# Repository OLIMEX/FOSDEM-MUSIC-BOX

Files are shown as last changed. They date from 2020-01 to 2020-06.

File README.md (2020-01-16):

# FOSDEM-MUSIC-BOX

Soldering kit programmable with Arduino IDE to play music

Product page: https://www.olimex.com/Products/Soldering-Kits/FOSDEM-MUSIC-BOX/open-source-hardware

## License
* Hardware is with CERN OHL v1.2 license
* Software is released under GPL3 License
* Documentation is released under CC BY-SA 3.0

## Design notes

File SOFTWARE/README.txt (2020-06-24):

FOSDEM-MUSIC-BOX software for Arduino IDE 1.8.10

Notice that the chip comes pre-loaded and to play the demo sound you don't need to 
reprogram it - just touch the light sensor!

You need to install the Olimex package first, else you would encounter compilation issues.

Please do the following:

1) Navigate to Main Menu --> File --> Preferences

In "Additional Boards Managers IRLs" add our JSON link:

https://raw.githubusercontent.com/OLIMEX/Arduino_configurations/master/AVR/package_olimex_avr_index.json

2) Navigate to Main Menu --> Tools --> Board --> Boards Manager (if you want to filter the packages you can type in the search "Olimex")

Select Olimex AVR boards and then install (up to 2020/01/30 the latest version is 2.0.2)

3) Main Menu --> Tools --> Board --> Olimexino-85

4) Compile

5) Unplug the board

6) Upload

7) Plug the board to the USB

8) Wait until the program uploads and then few seconds to leave the bootloader mode (at the start of the program the red LED should blink once)

9) After the LED blinks the program will get some samples from the light sensor and then when it's dimmed a simple track will be played (by default it's short version of Mario bros theme).

10) You can change it by comment/uncomment different tracks within the loop function or create your own using the available ones in the "Tracks" folder as an example.

YYYY/MM/DD
2020/01/30

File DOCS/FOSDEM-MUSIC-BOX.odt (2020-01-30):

FOSDEM MUSIC BOX – Assembly cheatsheet

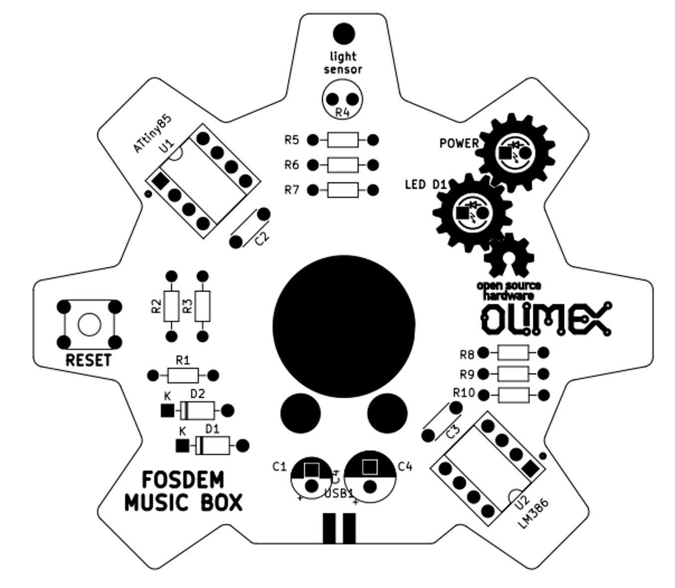
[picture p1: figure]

1. Resistors

R2, R3, R8 – 22R – 1/8W 5% - RED-RED-BLACK-GOLD

R1, R6, R9 – 1.5K – 1/8W 5% - BROWN-GREEN-RED-GOLD

R5, R7, R10 – 10K – 1/8W 5% - BROWN-BLACK-ORANGE-GOLD

2. Diodes

D1, D2 - 1N4148 – Warning! Polarity matters! Black stripe should be placed at the (K)athode side.

3. IC sockets

The first pin is marked!

U1 – ATTiny85 – Warning! Polarity matters! Orient properly!

U2 – LM386 – Warning! Polarity matters! Orient properly!

4. Button

RESET – 4-pin button

5. Speaker

SOLDER THE SPEAKER CAREFULLY! DO NOT OVERHEAT!

Hold soldering iron for NO more than 3 seconds soldering on pad or you will destroy the speaker.

6. USB connector – big metal shield pins soldering on bottom!

7. Capacitors

C2, C3 - 100nF X5R – 50VDC

C1 – 10uF 50VDC – Warning! Insert longer pin into circle pad.

C4 – 220uF 16VDC – Warning! Insert longer pin into circle pad.

8. LEDs

LED D1 – RED – Warning! Insert longer pin into circle pad

POWER – GREEN(clear) – Warning! Insert longer pin into circle pad

9. Light Sensor

R4 – 10K LDR

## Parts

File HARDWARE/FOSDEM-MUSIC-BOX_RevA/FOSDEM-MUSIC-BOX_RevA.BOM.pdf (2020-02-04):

FOSDEM-MUSIC-BOX_RevA

Designation | Quantity | Designator
ИС ATTINY85-20PU | 1 | U1
SNS-LDR5MM | 1 | R4
SPEAKER-29-8-0.25 | 1 | SPK1
КЛЮЧ ТАКТИЛЕН T1102 6x6x4.3mm | 1 | SW1
ДИОД 1N4148 | 2 | D1, D2
ИС LM386N-1 | 1 | U2
КОНДЕНЗАТОР 10 uF 16V | 1 | C1
КОНДЕНЗАТОР 100 nF 25 V - 2010 | 2 | C2, C3
КОНДЕНЗАТОР 220 uF 16 V | 1 | C4
РЕЗИСТОР 1.5 K 1/8W 5% | 3 | R1, R6, R9
РЕЗИСТОР 10 K 1/8W 5% | 3 | R5, R7, R10
РЕЗИСТОР 22 OHM 1/8W 5% | 3 | R2, R3, R8
СВЕТОДИОД 3 MM ЗЕЛЕН 4000 mcd | 1 | LED2 – POWER
СВЕТОДИОД 3 MM ЧЕРВЕН 4000 mcd | 1 | LED1 – LED D1
СЪЕДИНИТЕЛ USB-SDWH-4B-LF (USB-B ПРАВ) | 1 | USB1

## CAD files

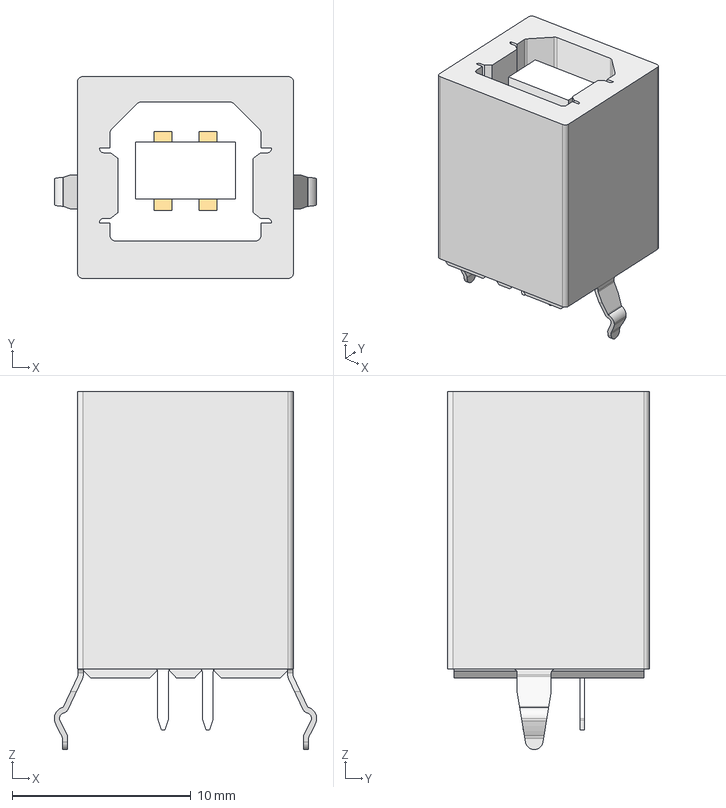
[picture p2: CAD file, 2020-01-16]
HARDWARE/FOSDEM-MUSIC-BOX_RevA/3d/usb_a-usb_b-top-c.stp
14.7 x 11.3 x 20.0 mm

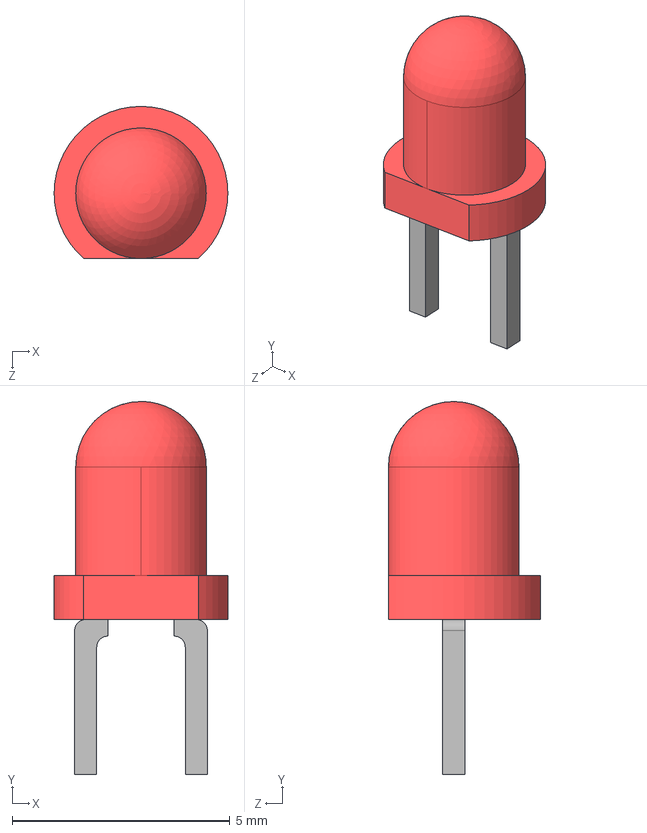
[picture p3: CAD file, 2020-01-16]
HARDWARE/FOSDEM-MUSIC-BOX_RevA/3d/REDLED.step
3.99 x 8.56 x 3.49 mm

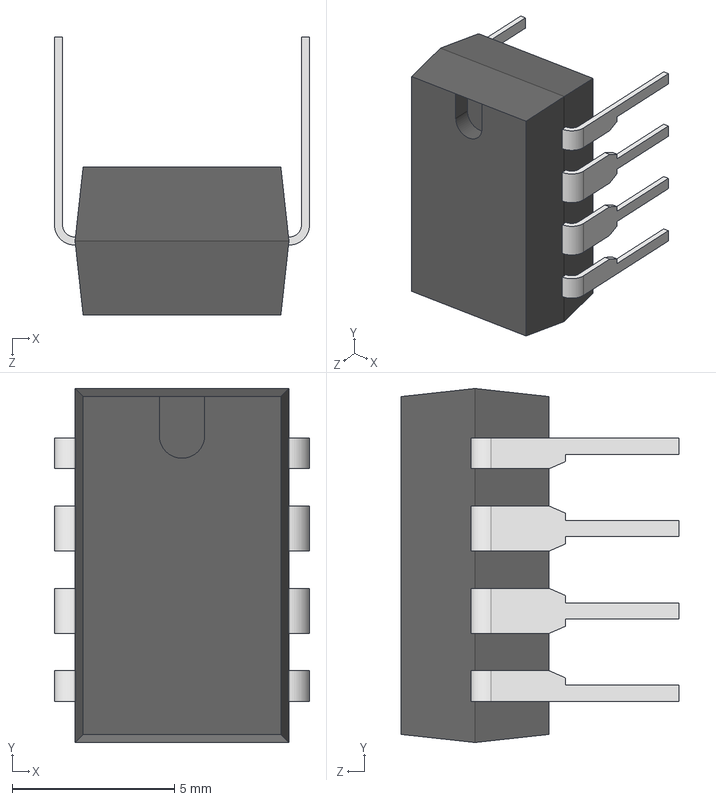
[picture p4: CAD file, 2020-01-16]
HARDWARE/FOSDEM-MUSIC-BOX_RevA/3d/DIP8_IC.step
7.87 x 10.9 x 8.58 mm

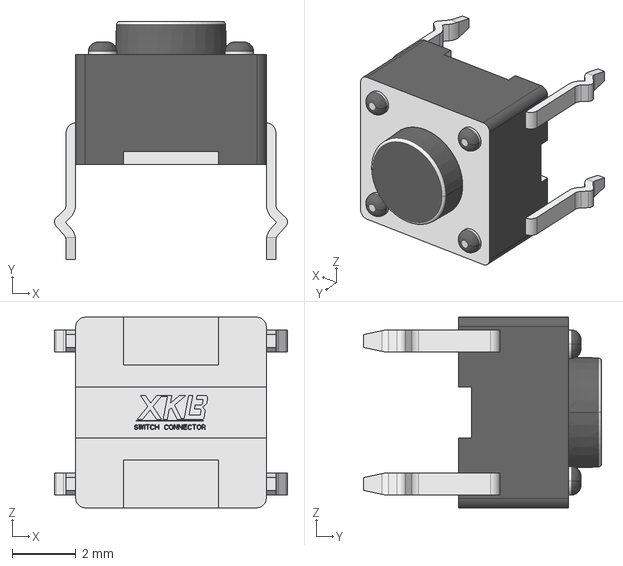
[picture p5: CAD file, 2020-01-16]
HARDWARE/FOSDEM-MUSIC-BOX_RevA/3d/t1102.step
7.34 x 7.50 x 6.00 mm

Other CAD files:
HARDWARE/FOSDEM-MUSIC-BOX_RevA/3d/GREENLED.step

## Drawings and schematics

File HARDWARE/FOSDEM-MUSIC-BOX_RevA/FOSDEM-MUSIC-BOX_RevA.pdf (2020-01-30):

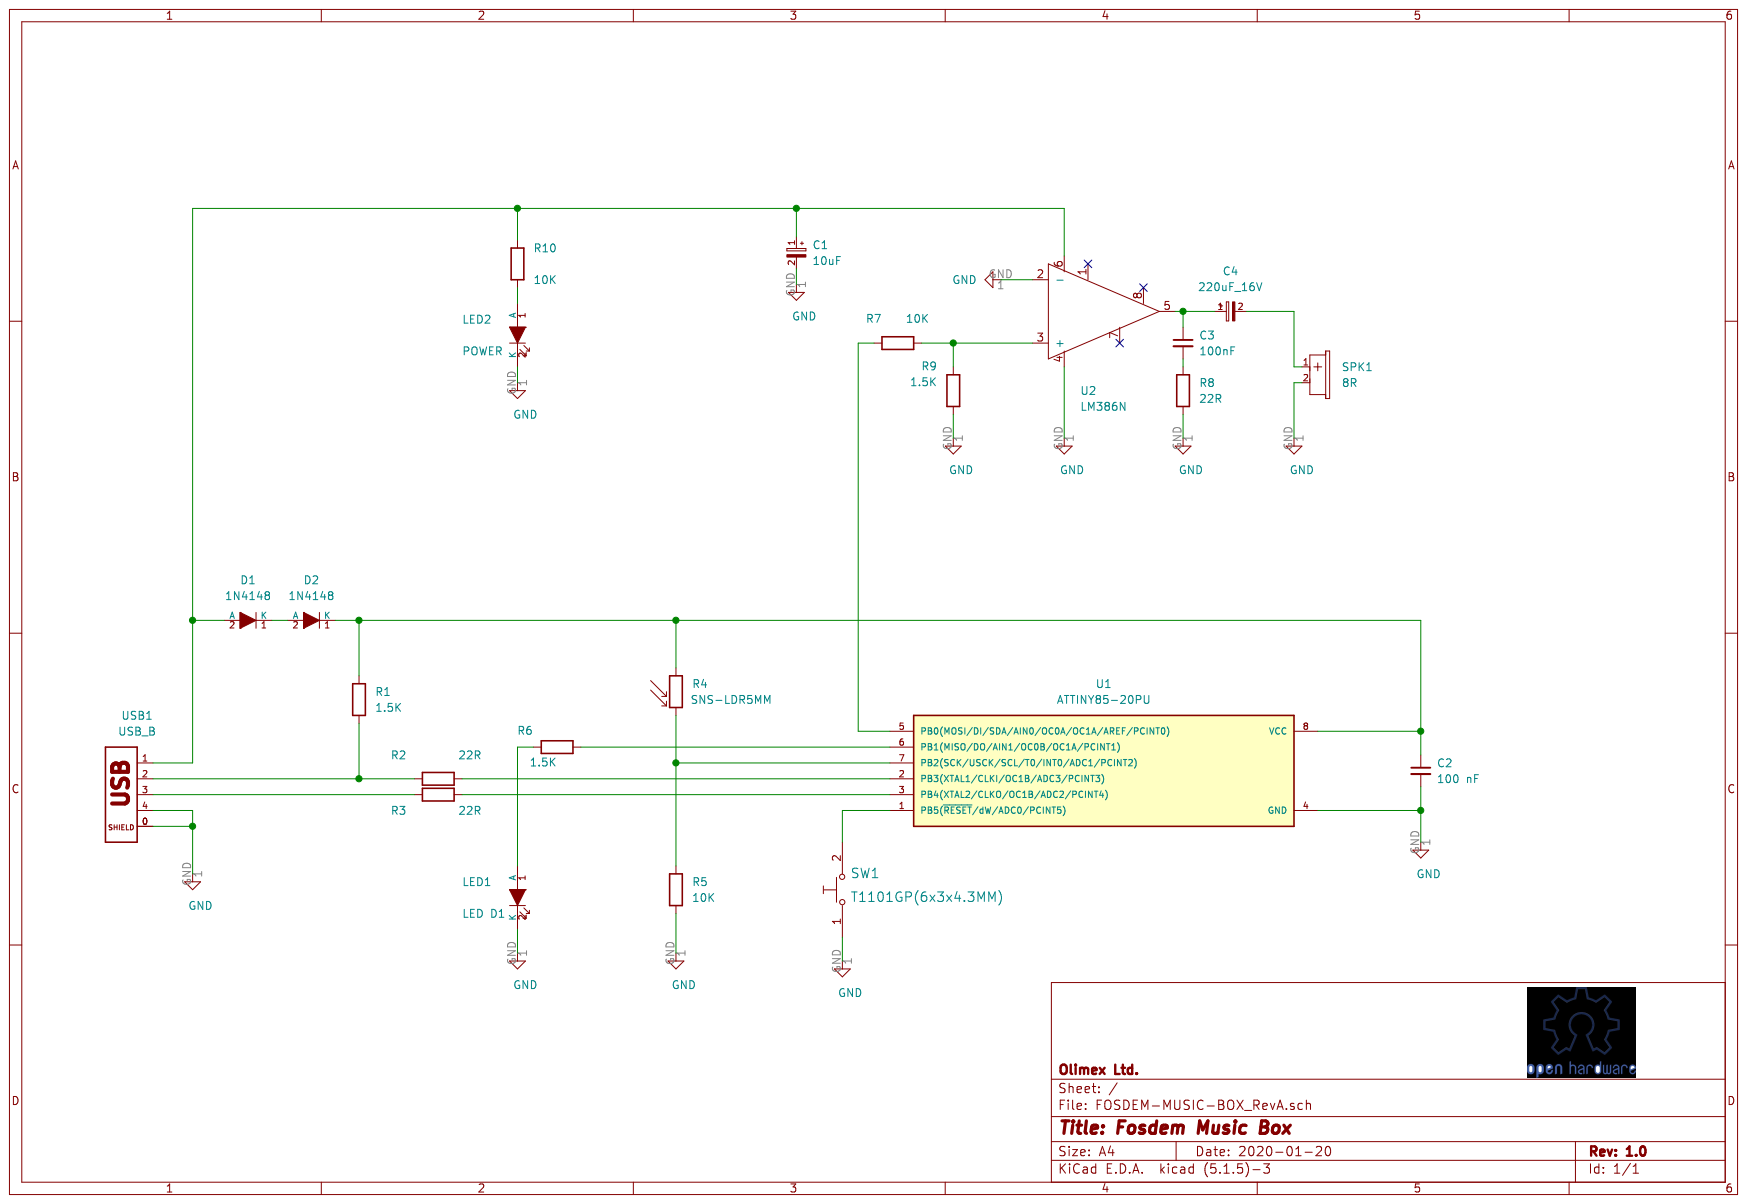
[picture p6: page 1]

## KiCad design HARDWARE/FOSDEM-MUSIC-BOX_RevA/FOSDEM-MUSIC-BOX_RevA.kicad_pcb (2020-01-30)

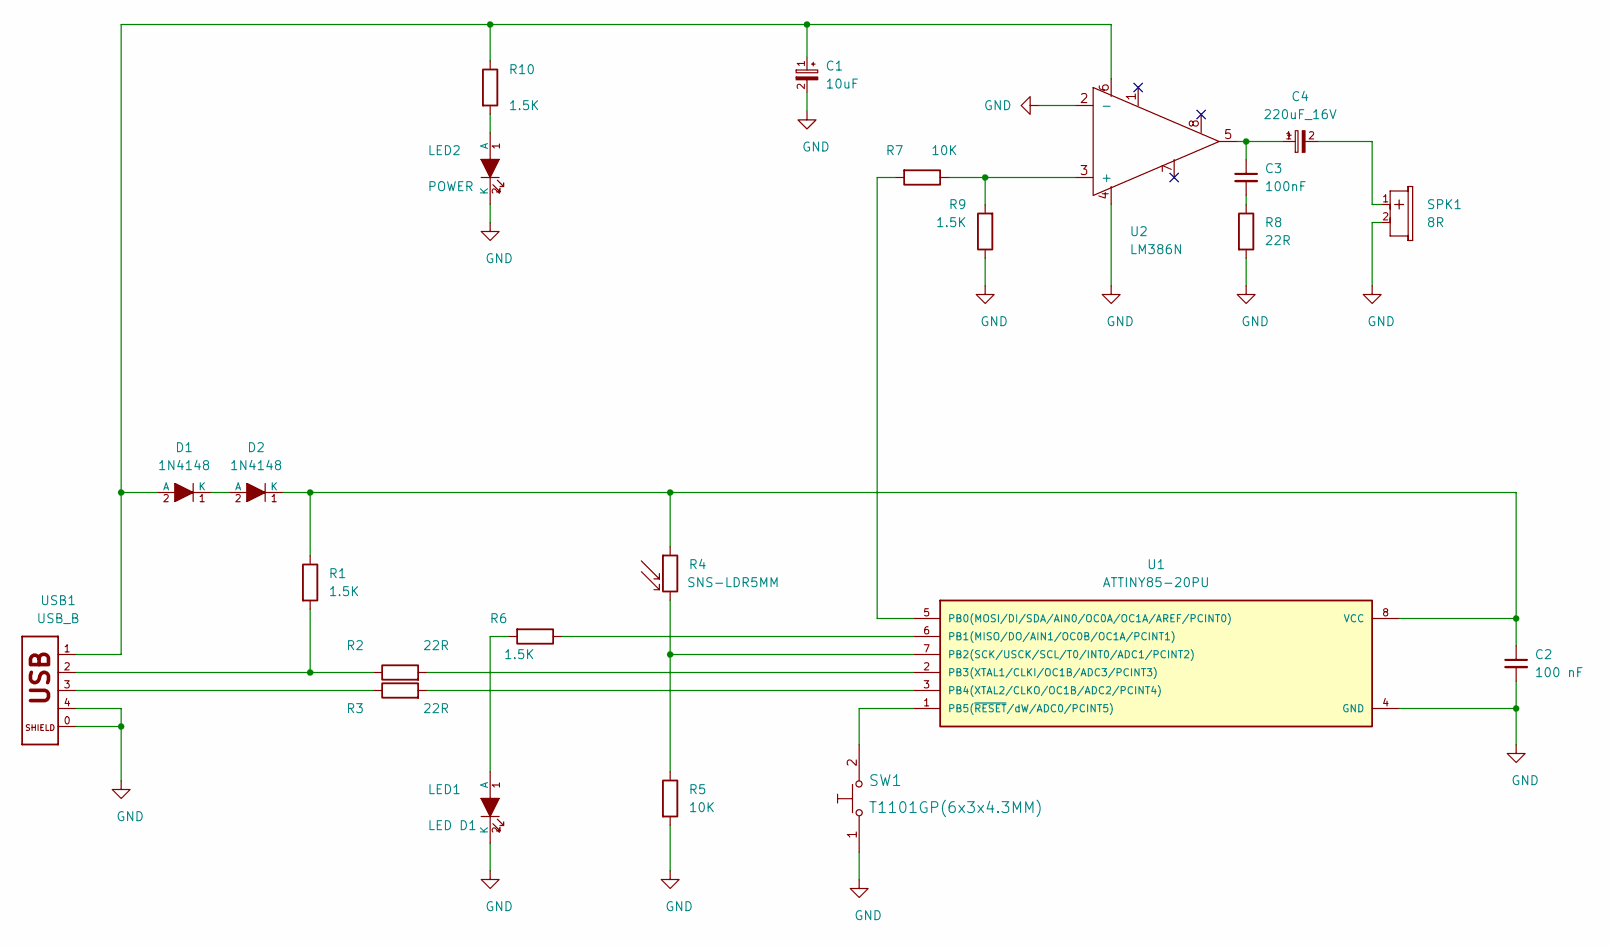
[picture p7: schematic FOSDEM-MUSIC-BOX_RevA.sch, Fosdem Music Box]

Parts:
C1: 10uF; CP_Radial_D5.0mm_P2.00mm
C2: 100 nF; C_Disc_D4.3mm_W1.9mm_P5.00mm
C3: 100nF; C_Disc_D4.3mm_W1.9mm_P5.00mm
C4: 220uF_16V; CP_Radial_D6.3mm_P2.50mm
D1, D2: 1N4148; D_DO-35_SOD27_P7.62mm_Horizontal
LED1: LED D1; LED-3mm-PTH-KA
LED2: POWER; LED-3mm-PTH-KA
R1, R6, R9, R10: 1.5K; R_Axial_DIN0204_L3.6mm_D1.6mm_P7.62mm_Horizontal
R2, R3, R8: 22R; R_Axial_DIN0204_L3.6mm_D1.6mm_P7.62mm_Horizontal
R4: SNS-LDR5MM; R_PHOTO
R5, R7: 10K; R_Axial_DIN0204_L3.6mm_D1.6mm_P7.62mm_Horizontal
SPK1: 8R; SPEAKER_28mm
SW1: T1101GP(6x3x4.3MM); T1102SMD
U1: ATTINY85-20PU; DIP-8_W7.62mm_Socket
U2: LM386N; DIP-8_W7.62mm_Socket
USB1: USB_B; USB-B-EDGE

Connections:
GND: C1.2 (-), C2.2, LED1.2 (K), LED2.2 (K), R5.2, R8.2, R9.1, SPK1.2 (MINUS), SW1.1, U1.4 (GND), U2.2 (-), U2.4, USB1.0 (5), USB1.4
unnamed: C1.1 (+), D1.2 (A), R10.1, U2.6, USB1.1
unnamed: C3.1, C4.1 (+), U2.5
unnamed: C3.2, R8.1
unnamed: C4.2 (-), SPK1.1 (PLUS)
unnamed: C2.1, D2.1 (K), R1.1, R4.1, U1.8 (VCC)
unnamed: D1.1 (K), D2.2 (A)
unnamed: LED1.1 (A), R6.2
unnamed: LED2.1 (A), R10.2
unnamed: R1.2, R2.1, USB1.2
unnamed: R2.2, U1.2 (PB3(XTAL1/CLKI/OC1B/ADC3/PCINT3))
unnamed: R3.1, USB1.3
unnamed: R3.2, U1.3 (PB4(XTAL2/CLKO/OC1B/ADC2/PCINT4))
unnamed: R6.1, U1.6 (PB1(MISO/DO/AIN1/OC0B/OC1A/PCINT1))
unnamed: R4.2, R5.1, U1.7 (PB2(SCK/USCK/SCL/T0/INT0/ADC1/PCINT2))
unnamed: R7.1, R9.2, U2.3 (+)
unnamed: R7.2, U1.5 (PB0(MOSI/DI/SDA/AIN0/OC0A/OC1A/AREF/PCI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)
unnamed: SW1.2, U1.1 (PB5(~RESET~/dW/ADC0/PCINT5))

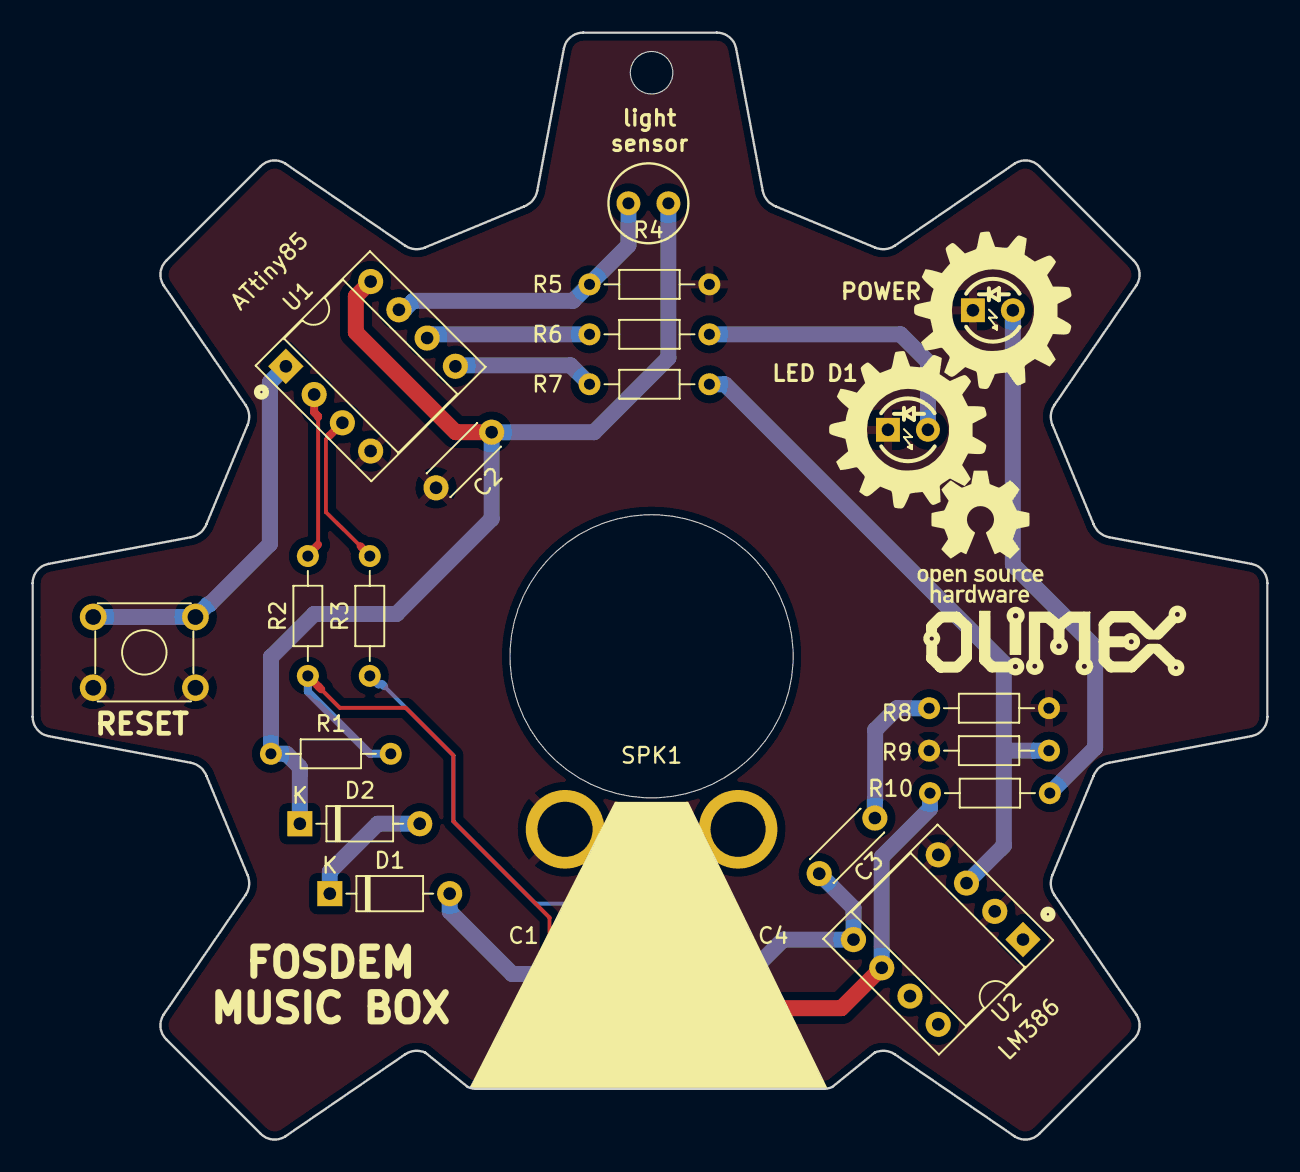
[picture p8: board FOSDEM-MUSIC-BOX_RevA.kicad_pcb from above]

Board: 2 copper layers, 78.5 x 70.4 mm, 24 parts (0 on the bottom side), 18 nets.

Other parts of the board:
MountingHole: NPTH_2.7mm

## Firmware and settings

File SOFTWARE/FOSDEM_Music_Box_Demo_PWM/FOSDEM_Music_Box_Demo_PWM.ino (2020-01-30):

#include "Notes.h"
#include "Tracks/All_Tracks.h"
#include "Speaker.h"

// the following functions just call the Play (in Speaker.cpp) function using the notes array from the respective file in "Tracks" folder
// Note: Since not all of them are made polyphonic, for some of them both channels are playing the same! If you want to play polyphonic on them edit the respective file
void Imperial_March ()
{
  Play (IM1_Note, IM1_Note, IM1_Duration, IM1_Tempo);
  Play (IM2_Note, IM2_Note, IM2_Duration, IM2_Tempo);
  Play (IMV1_Note, IMV1_Note, IMV1_Duration, IMV1_Tempo);
  Play (IM2_Note, IM2_Note, IM2_Duration, IM2_Tempo);
  Play (IMV2_Note, IMV2_Note, IMV2_Duration, IMV2_Tempo);
}

void Amazing_Grace ()
{
  Play (AG1_Note, AG1_Note, AG1_Duration, AG1_Tempo);
  Play (AG2_Note, AG2_Note, AG2_Duration, AG2_Tempo);
}

void Mario_Bros_Underwater ()
{
  Play (MBU1_Note, MBU1_Note, MBU1_Duration, MBU1_Tempo);
  Play (MBU2_Note, MBU2_Note, MBU2_Duration, MBU2_Tempo);
  Play (MBU3_Note, MBU3_Note, MBU3_Duration, MBU3_Tempo);
  Play (MBU4_Note, MBU4_Note, MBU4_Duration, MBU4_Tempo);
}

void Silent_Night_Holy_Night ()
{
  Play (SNHN1_Note, SNHN1_Note, SNHN1_Duration, SNHN1_Tempo);
  Play (SNHN2_Note, SNHN2_Note, SNHN2_Duration, SNHN2_Tempo);
  Play (SNHN3_Note, SNHN3_Note, SNHN3_Duration, SNHN3_Tempo);
}

void Test_audio ()
{
  Play (Test1_Note, Test1_Note, Test1_Duration, Test1_Tempo);
}

void Mario_Bros ()
{
  //     Channel0    Channel1
  Play (MB1_NoteC0, MB1_NoteC1, MB1_Duration, MB1_Tempo);
  Play (MB3_NoteC0, MB3_NoteC1, MB3_Duration, MB3_Tempo);
  Play (MB2_NoteC0, MB2_NoteC1, MB2_Duration, MB2_Tempo);
  Play (MB3_NoteC0, MB3_NoteC1, MB3_Duration, MB3_Tempo);
  Play (MB2_NoteC0, MB2_NoteC1, MB2_Duration, MB2_Tempo);
}

void Ode_of_Joy ()
{
  //     Channel0     Channel1
  Play (OOJ1_NoteC1, OOJ1_NoteC2, OOJ1_Duration, OOJ1_Tempo);
  Play (OOJ2_NoteC1, OOJ2_NoteC2, OOJ2_Duration, OOJ2_Tempo);
  Play (OOJ3_NoteC1, OOJ3_NoteC2, OOJ3_Duration, OOJ3_Tempo);
  Play (OOJ4_NoteC1, OOJ4_NoteC2, OOJ4_Duration, OOJ4_Tempo);
}

// at start we are trying to set a "default" value for the photodiode input for the environment and this is the number of samples to take average
#define SAMPLES 20
long int Light_Sensor_Average = 0;  // variable to store the 
int Read_Light_Sensor ()  // reading analog value of the on ADC1 (photodiode)
{
  return analogRead (A1); // A1 --> ADC1 (PB2)
}

void setup()
{
  PWM_Init ();  // initialization of the PWM
  pinMode (1, OUTPUT);  // LED set as output
  // Blinks the LED once to indicate end of the bootloader mode
  digitalWrite (1, HIGH);
  delay (1000);
  digitalWrite (1, LOW);
  // taking the average of the photodiode input to take the average
  for (int i=0; i<SAMPLES; i++)
    Light_Sensor_Average = Light_Sensor_Average + Read_Light_Sensor();
  Light_Sensor_Average = Light_Sensor_Average / SAMPLES;
}

void loop ()
{
  if (Read_Light_Sensor() < Light_Sensor_Average - 0x30)  // if the photodiode sense dimming of the light by a certain value
  {
    // playint any of the tracks
    Mario_Bros ();
    //Ode_of_Joy ();
    //Imperial_March ();
    //Amazing_Grace ();
    //Mario_Bros_Underwater ();
    //Silent_Night_Holy_Night ();
    //Test_audio ();
  }
}

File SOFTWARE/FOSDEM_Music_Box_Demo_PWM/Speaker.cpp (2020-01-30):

#include "Arduino.h"
#include "Speaker.h"
#include "Notes.h"
#include <avr/pgmspace.h>

#define VOLUME  // this macros is defined if you want to here the beginning of the notes stronger, used to distinguish 2 consecutive equal notes

// the following variables are used to form the sine (doubled variables for the two channels)
// phaseInc - amount of steps on the sine table to be skipped based on the desired frequency
// phaseReg - the counter in which the phaseInc value is added and summed
// Volume - volume of the sound (it's stronger on the start of the note and gets weaker after that)
// sin - additional variable used for the increased volume at the start of the note
volatile unsigned int phaseInc1, phaseInc2, Volume1, Volume2; 
unsigned int phaseReg1, phaseReg2;
unsigned char sin1, sin2;

volatile unsigned long int Counter=0; // Counter used to measure time (since both timers are used to generate the sine)

// generated sine table from 0 to 255 to determine the duty cycle of the PWM (256 elements total)
const unsigned char SINE_TABLE[]=
{
  128, 131, 134, 137, 140, 143, 146, 149, 152, 156, 159, 162, 165, 168, 171, 174,
  176, 179, 182, 185, 188, 191, 193, 196, 199, 201, 204, 206, 209, 211, 213, 216,
  218, 220, 222, 224, 226, 228, 230, 232, 234, 236, 237, 239, 240, 242, 243, 245,
  246, 247, 248, 249, 250, 251, 252, 252, 253, 254, 254, 255, 255, 255, 255, 255,
  255, 255, 255, 255, 255, 255, 254, 254, 253, 252, 252, 251, 250, 249, 248, 247,
  246, 245, 243, 242, 240, 239, 237, 236, 234, 232, 230, 228, 226, 224, 222, 220,
  218, 216, 213, 211, 209, 206, 204, 201, 199, 196, 193, 191, 188, 185, 182, 179,
  176, 174, 171, 168, 165, 162, 159, 156, 152, 149, 146, 143, 140, 137, 134, 131,
  127, 124, 121, 118, 115, 112, 109, 106, 103,  99,  96,  93,  90,  87,  84,  81,
   79,  76,  73,  70,  67,  64,  62,  59,  56,  54,  51,  49,  46,  44,  42,  39,
   37,  35,  33,  31,  29,  27,  25,  23,  21,  19,  18,  16,  15,  13,  12,  10,
    9,   8,   7,   6,   5,   4,   3,   3,   2,   1,   1,   0,   0,   0,   0,   0,
    0,   0,   0,   0,   0,   0,   1,   1,   2,   3,   3,   4,   5,   6,   7,   8,
    9,  10,  12,  13,  15,  16,  18,  19,  21,  23,  25,  27,  29,  31,  33,  35,
   37,  39,  42,  44,  46,  49,  51,  54,  56,  59,  62,  64,  67,  70,  73,  76,
   79,  81,  84,  87,  90,  93,  96,  99, 103, 106, 109, 112, 115, 118, 121, 124
};


// interrupt on timer1 compare (should enter every 20us)
ISR(TIMER1_COMPA_vect)
{
  // sum up the current phaseReg with the following phaseInc (which is based on the frequency of the next tone)
  phaseReg1 += phaseInc1;
  phaseReg2 += phaseInc2;
  // get the value from the sine table (since phaseReg is 16 bits we take the high byte
  sin1=SINE_TABLE[(uint8_t)(phaseReg1 >> 8)];
  sin2=SINE_TABLE[(uint8_t)(phaseReg2 >> 8)];
  
#if defined VOLUME
  // increase/decrease the duty cycle of the PWM based on the strength of the sound 
  // shifting of Volume1/2 is with 10 bits instead 8 decrease the volume silencing (otherwise longer notes get silent at the end)
  if (sin1 > 127)
  {
    sin1 -= (Volume1>>10);
    if (sin1 < 127)
      sin1 = 127;
  }
  else
  {
    sin1 += (Volume1>>10);
    if (sin1 > 127)
      sin1 = 127;
  }

  if (sin2 > 127)
  {
    sin2 -= (Volume2>>10);
    if (sin2 < 127)
      sin2 = 127;
  }
  else
  {
    sin2 += (Volume2>>10);
    if (sin2 > 127)
      sin2 = 127;
  }

  if (Volume1<32767)
    Volume1++;
  if (Volume2<32767)
    Volume2++;
#endif 
  OCR0A = (sin1+sin2)/2; // update TC0 output compare register to generate the required duty cycle of the PWM

  Counter++;  // this counter is used for the MyDelay function
}

void PWM_Init ()
{
  pinMode (SPEAKER, OUTPUT);

  // Timer 0
  TCCR0A = 0x83;  // OC0A clear on compare, set at bottom, Fast PWM, page 78
  TCCR0B = 0x01;  // no prescaler
  OCR0A = 0;      // start with duty cycle = 0%

  // Timer 1
  TCCR1 = 0x83 ;  // CTC - clear timer on match A; prescaler = 4, page 89
  OCR1C = (F_CPU / 4 / F_UPDATE - 1); // 79
  TIMSK |= 0x40;  // Timer/Counter1 Output Compare Interrupt Enable

  phaseReg1 = 0;
  phaseReg2 = 0;

  sei();  // Global interrupt enable
}

// loading values into the phaseInc variables used in the interrupt based on the desired frequencies
void Play_Tone (int Freq1, int Freq2)
{
  // load the required frequency into the increment variables
  phaseInc1 = ((long int)Freq1 <<16) / F_UPDATE;  
  phaseInc2 = ((long int)Freq2 <<16) / F_UPDATE;
  Volume1 = 0;
  Volume2 = 0;
}

// custom delay function since the original delay function uses timer1, but since we use it for generating interrupt we should do our own
void MyDelay (volatile unsigned long int Period)  // ms
{
  unsigned long int EndTime = Counter + Period*(F_UPDATE/1000); // 1 cycle in loop is ~20us; 20*50 = 1000us * Period
  while (Counter != EndTime);
}

// Playing two notes at the same time wtih the specified duration
void Note (int Channel0_Frequency, int Channel1_Frequency, int Duration)
{
  Play_Tone (Channel0_Frequency, Channel1_Frequency);
  MyDelay(Duration);
}
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

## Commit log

2020-01-16 initial upload hardware, software, licensee
    [DIP8_IC.step, FOSDEM-MUSIC-BOX_RevA.kicad_pcb, FOSDEM-MUSIC-BOX_RevA.sch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]
2020-01-16 assembly docs
2020-02-04 Added BOM

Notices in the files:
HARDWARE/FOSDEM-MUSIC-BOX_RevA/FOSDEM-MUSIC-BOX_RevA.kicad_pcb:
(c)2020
